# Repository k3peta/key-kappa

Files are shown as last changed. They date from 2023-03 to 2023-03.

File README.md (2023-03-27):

# key-kappa
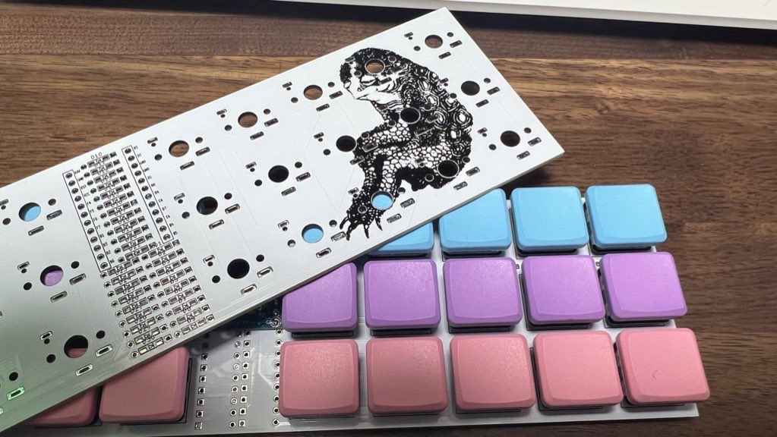
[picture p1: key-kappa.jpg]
key-kappa画像


神沼三平太が趣味で作った親指レス30キーの自作キーボードのデータです。

ケースなしPCBにゴム足というチープなやつです。めっちゃ薄い。そして角が痛い。

名称の由来はGherkinをパクった感じだから。要はキュウリをパクるような奴からの連想で河童です。結局完全オリジナルになってしまいましたが。

ぎぎぎ。わしは薄くて軽いGherkin配列のキーボードが欲しかったんじゃ……。

## キーボードの入手方法

KiCadのデータとガーバーファイルのZIPファイルを置いておいたので、何とかしてください。たぶんそのまま業者に発注できます。組み立てるには半田付けのスキルが必要です。

完成させるにはKailhロープロファイルスイッチ（Choc v1またはv2に対応）が30個必要です。キートップも同数必要です。他にはProMicro1個とダイオードが30個、あとは適宜ゴム足が必要になります。個人的には表面実装型のダイオードを裏面に並べる方が表面が綺麗なのでおすすめ。ProMicroを付けるときはピンヘッダでもいけるけど、コンスルー対応なのでお好みで何とかしてください。

## ファームウェア

ファームウェアは現時点でのVIA対応を諦めているので、GUIでのキーの変更とかはしばらく落ち着いてから。従って現状QMK Firmwareでソースからコンパイルしてください。コンパイル済みのhexファイル（kappa_default.hex）も置いておきます。なお書き込みはToolboxでよしなにしてください。

## ビルド方法

- まず適宜ダイオードの足を折り、線の入っている方を四角い穴の方にして足を差し込み、30本ハンダづけします。
- ProMicroを取り付けるために、ピンヘッダを上から基板に差し込んでハンダづけします。ピンヘッダは短い側を基板に差し込むといいでしょう。
- ProMicroを上から被せるようにピンヘッダを通してハンダづけします。
- キースイッチを30個差し込んでハンダづけします。ハンダづけを終えたらキーキャップもつけましょう。
- QMK Toolboxでファームウェア（配布されているkappa.hex）を焼きます。リセットボタンがないのでProMocroの向かって右上のGNDとRSTをショートさせてください。
- 完成！

## デフォルトのキー配列

下の画像はkey-kappaのデフォルトのキーマップ（河童配列）です。左右の薬指の位置にそれぞれレイヤーキーがあります。右側のレイヤーキーを押しながら他のキーを押すと、レイヤー１（キーの左上の記号）が入力されます。左側のレイヤーキーはレイヤー２（キーの右下の記号）が入力できます。いわゆる順手シフトで記号とファンクションキー、逆手シフトで数字とカーソルキーという感じ。

日本語を打つ場合に多用される「」、。ーの五種類の記号については。、右手でレイヤーキーを押しながら左手のホームポジションで打ちます。あとの記号は適当に覚えてください。

あとキー長押しでキー側面のキーが入力できます。

MacユーザなのでKarabiner-Elementsを利用して「左右のコマンドキーを英数キーとかなキーとして使う」ように設定している関係で、左右のレイヤーキーにGUIキーを仕込んであります。要するにレイヤー１キーを長押ししながらレイヤー2キーを押すと「英数」キーが入力され。逆にレイヤー2キーを長押ししながらレイヤー1キーを押すと、「かな」キーが入力されるようにしてあります。

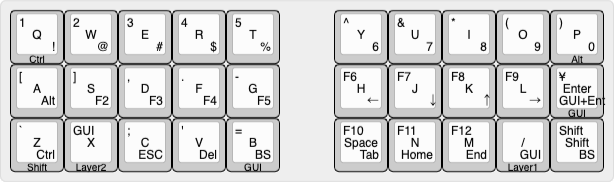
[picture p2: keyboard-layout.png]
デフォルトのキーマップ画像


この配列を快適に打ちたかっただけです。

参考までに河童配列を適用したPIPI GHERKINのKMK用設定も置いておきます。

## その他カスタマイズ

### BLE Micro Pro用のJSNファイルの実験の成果とか

試行錯誤の結果を置いときます。実機が次元の彼方に旅立っていったので、誰か実験してみてください。多分いけるんで。

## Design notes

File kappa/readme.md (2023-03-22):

# kappa1

kappa1

*A short description of the keyboard/project*

* Keyboard Maintainer: [k3peta](https://github.com/k3petga)
* Hardware Supported: *The PCBs, controllers supported*
* Hardware Availability: *Links to where you can find this hardware*

Make example for this keyboard (after setting up your build environment):

    make kappa1:default

Flashing example for this keyboard:

    make kappa1:default:flash

See the [build environment setup](https://docs.qmk.fm/#/getting_started_build_tools) and the [make instructions](https://docs.qmk.fm/#/getting_started_make_guide) for more information. Brand new to QMK? Start with our [Complete Newbs Guide](https://docs.qmk.fm/#/newbs).

## Bootloader

Enter the bootloader in 3 ways:

* **Bootmagic reset**: Hold down the key at (0,0) in the matrix (usually the top left key or Escape) and plug in the keyboard
* **Physical reset button**: Briefly press the button on the back of the PCB - some may have pads you must short instead
* **Keycode in layout**: Press the key mapped to `QK_BOOT` if it is available

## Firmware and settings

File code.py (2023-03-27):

print("Starting")

import board

from kmk.kmk_keyboard import KMKKeyboard
from kmk.keys import KC
from kmk.scanners import DiodeOrientation
from kmk.modules.layers import Layers
from kmk.modules.modtap import ModTap

keyboard = KMKKeyboard()
modtap = ModTap()
layers_ext = Layers()
keyboard.modules = [layers_ext, modtap]


# 列ピンの定義
keyboard.col_pins = (board.GP2, board.GP3, board.GP4, board.GP5, board.GP6, board.GP7)
# 行ピンの定義
keyboard.row_pins = (board.GP8, board.GP9, board.GP10, board.GP11, board.GP12)
keyboard.diode_orientation = DiodeOrientation.COL2ROW

CTL_Q = KC.MT(KC.Q, KC.LCTL)
ALT_P = KC.MT(KC.P, KC.LALT)
GUI_ENT = KC.MT(KC.ENT, KC.LGUI)
SFT_Z = KC.MT(KC.Z, KC.LSFT)
LT1_SLSH = KC.LT(1, KC.SLSH)
LT2_X = KC.LT(2, KC.X)


keyboard.keymap = [
    [
        CTL_Q,    KC.W,    KC.E,    KC.R,   KC.T,     KC.Y,    KC.U,    KC.I,    KC.O,    ALT_P,
        KC.A,    KC.S,    KC.D,    KC.F,   KC.G,     KC.H,    KC.J,    KC.K,    KC.L,    GUI_ENT,
        SFT_Z,    LT2_X,    KC.C,    KC.V,   KC.B,     KC.SPC,    KC.N,    KC.M,    LT1_SLSH,    KC.RSFT
    ],
    [
        KC.N1,   KC.N2,   KC.N3,   KC.N4,   KC.N5,   KC.CIRC,   KC.AMPR,   KC.ASTR,   KC.LPRN,   KC.RPRN,
        KC.LBRC,    KC.RBRC,    KC.COMM,    KC.DOT,   KC.MINS,     KC.F6,    KC.F7,    KC.F8,    KC.F9,    KC.BSLS,
        KC.GRAVE,    KC.LGUI,    KC.SCOLON,    KC.QUOT,   KC.EQL,     KC.F10,    KC.F11,    KC.F12,    KC.TRNS,    KC.RSFT
    ],
    [
        KC.EXLM,   KC.AT,   KC.HASH,   KC.DLR,   KC.PERC,   KC.N6,   KC.N7,   KC.N8,   KC.N9,   KC.N0,
        KC.ALT,   KC.F2,   KC.F3,   KC.F4,   KC.F5,     KC.LEFT,    KC.DOWN,    KC.UP,    KC.RGHT,    KC.RGUI(KC.ENT),
        KC.LCTL,    KC.TRNS,    KC.ESC,    KC.DEL,   KC.BSPC,     KC.TAB,    KC.HOME,    KC.END,    KC.RGUI,    KC.BSPC
    ],
]

if __name__ == '__main__':
    keyboard.go()

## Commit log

2023-03-22 りどみちょっと描いた。
2023-03-22 河童画像
2023-03-22 今後の課題を含めて。
2023-03-22 BLE対応用
2023-03-22 QMK Firmware関係
2023-03-22 バグとり
2023-03-22 readmeに加筆
2023-03-27 河童配列（KMK PIPI GHERKIN用）
